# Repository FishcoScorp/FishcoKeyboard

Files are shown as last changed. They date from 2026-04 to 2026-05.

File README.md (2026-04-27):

# FishcoKeyboard
My keyboard for the program fallout by hackclub\
\
This keyboard was made with convieniece in mind, with 15 customizable macro keys (4 on left 11 on right) as well as a volume dial and small screen. 

# Table of Contents
Bill of Materials: https://github.com/FishcoScorp/FishcoKeyboard/edit/main/README.md#:~:text=Build_Files-,BOM,-.csv \
Photo Gallery: https://github.com/FishcoScorp/FishcoKeyboard/edit/main/README.md#:~:text=Fallout%20Zine.md-,Photo,-Gallery.md \
Code: https://github.com/FishcoScorp/FishcoKeyboard/edit/main/README.md#:~:text=README.md-,code,-.py \
Zine: https://github.com/FishcoScorp/FishcoKeyboard/edit/main/README.md#:~:text=BOM.csv-,Fallout,-Zine.md \
\
I am also in the process of working on a software that will interface with the keyboard and allow me to easily switch macro keys and the display on the screen, and make it easy to flash new code to the keyboard.\
\
Fallout Zine (1)
\
How to put it together! \
I used Kicad, and started by making a matrix with all the keys at about where I thought they were on a subsheet. That looks like this (Don't forget to add diodes too!!!) This works by wiring rows and columns which, when shorted by pressing a button, can be identified and pinpointed similar to using x and y on a graph so that it sends the correct input to your device!
Screenshot 2026-04-27 at 12 48 47 PM
\
Then I have the main schematic sheet, where I make all the rest of the connections. Using tags I connect the matrix to the ESP and also the screen and rotary encoder. Notice I connect the grounds of the latter two elements using a GND tag. This is because I am going to use a gnd fill later, which means the board will be coated in a thin layer of copper, removing the need for GND connections as this coating will serve that purpose.
Screenshot 2026-04-27 at 1 09 43 PM
\
Now bring it over to the PCB editor, where you will shape what your keyboard looks like. You can use an app called KB Placer by creating a layout beforehand on the website http://keyboard-layout-editor.com/ and then importing the JSON to KB placer. However, this did not work for me so I had to manually place everything and create the outline of the keyboard myself. I then connected the matrix, rotary encoder, and screen before adding the GND fill (the red in this photo)
Screenshot 2026-04-13 at 10 05 19 PM
\
Then it was time to cad a case. I used Fusion, using the exported .step file model to draw an outline for my case. Then I added some standoffs using the PCB as a reference with the screw holes I had placed earlier, ensuring stabilization but not breaking the PCB. In this case I made so both the bottom and top had walls so that it would look clean and sleek. I also sunk the keys into the keyboard a little so that it would look slim and cool. I also added a window into the ESP cause I think it would look really cool to be abe to see it, a little glimpse into the work/electronics that are required to make this a reality.
Screenshot 2026-04-16 at 11 17 34 AM
\ 
After this I designed my zine and submitted it, and here we are!

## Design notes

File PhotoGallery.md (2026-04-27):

Screenshot 2026-04-13 at 10 05 19 PM
Finished PCB design of the keyboard
Screenshot 2026-04-13 at 10 13 47 PM
Sketching out the design of the keyboard using the PCB as a reference in Fusion
Screenshot 2026-04-14 at 3 09 46 PM
Left a small gap for standoffs/avoid crushing diodes
Screenshot 2026-04-14 at 3 10 09 PM
Case bottom designed
Screenshot 2026-04-14 at 3 10 23 PM
Case bottom showing off standoff locations
Screenshot 2026-04-16 at 11 07 59 AM
Screenshot 2026-04-16 at 11 09 02 AM
Keys mapped out with fusion
Screenshot 2026-04-16 at 11 17 34 AM
Completed keyboard layout and holes
Screenshot 2026-04-20 at 1 21 00 PM
somehow managed to fit it all on one build plate using an H2D at my school

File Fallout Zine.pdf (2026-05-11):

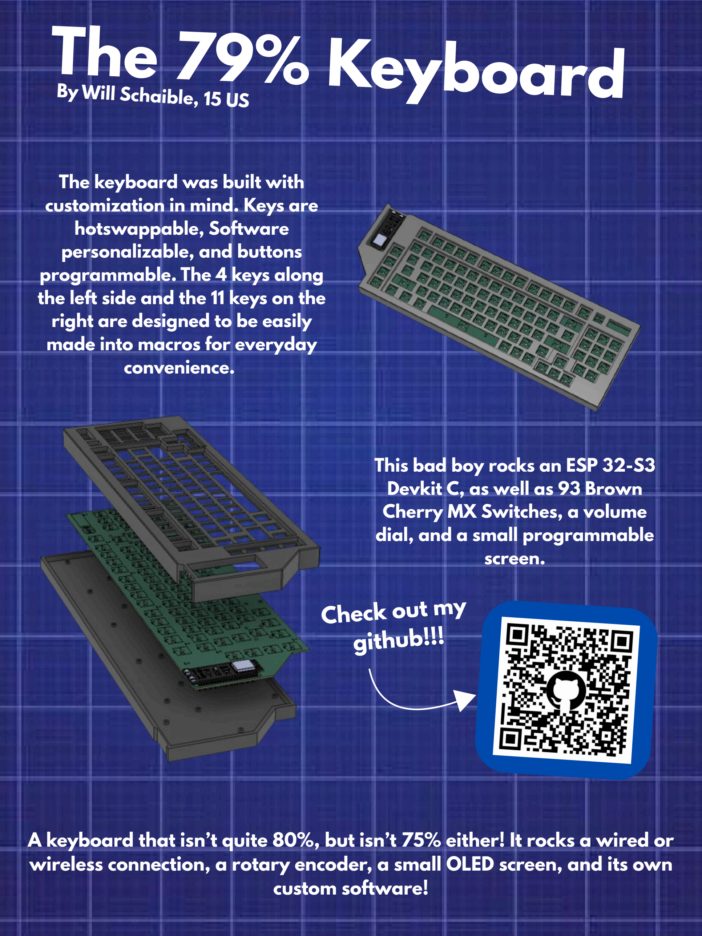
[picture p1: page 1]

T

By W

h

ill S

e

chaib

7

le, 15

9

US

# % Keyboard

A keyboard that isn’t quite 80%, but isn’t 75% either! It rocks a wired or wireless connection, a rotary encoder, a small OLED screen, and its own custom software!

The keyboard was built with customization in mind. Keys are hotswappable, Software
personalizable, and buttons programmable. The 4 keys along the left side and the 11 keys on the right are designed to be easily made into macros for everyday convenience.

This bad boy rocks an ESP 32-S3 Devkit C, as well as 93 Brown Cherry MX Switches, a volume dial, and a small programmable screen.

## Check out my github!!!

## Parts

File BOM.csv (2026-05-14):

Item | Quantity | Details | Unit Cost (USD) | Total Cost (USD) | Link
M2 Screws (3mm) | 22 | Mounting screws for PCB | $0.99 | $0.99 | https://www.aliexpress.us/item/3256802317314157.html?curPageLogUid=etorZpcxQGNX
Cherry MX Switches (Cheaper here) | 93 | Cherry MX2A Brown 55g tactile | $0.39 | $39.00 | https://mechanicalkeyboards.com/products/cherry-mx2a-brown-55g-tactile
ESP32-S3 Dev Board | 1 | ESP32-S3-DevKitC-1-N8 (8MB Flash + 8MB PSRAM) | $15.95 | $15.95 | https://www.adafruit.com/product/5312
Rotary Encoder | 1 | Standard rotary encoder | $6.58 | $6.58 | https://www.aliexpress.us/item/3256809594557634.html
OLED Screen | 1 | Small OLED display | $3.86 | $3.86 | https://www.aliexpress.us/item/3256806514926637.html
PCB Manufacturing | 1 | PCB + shipping from JLCPCB | $78.39 | $78.39 | https://jlcpcb.com/
PETG Filament (1kg) | 1 | PETG Basic with spool | $22.99 | $22.99 | https://us.store.bambulab.com/products/petg-basic?id=703099511296864275
TOTAL |  |  |  | $$167.76

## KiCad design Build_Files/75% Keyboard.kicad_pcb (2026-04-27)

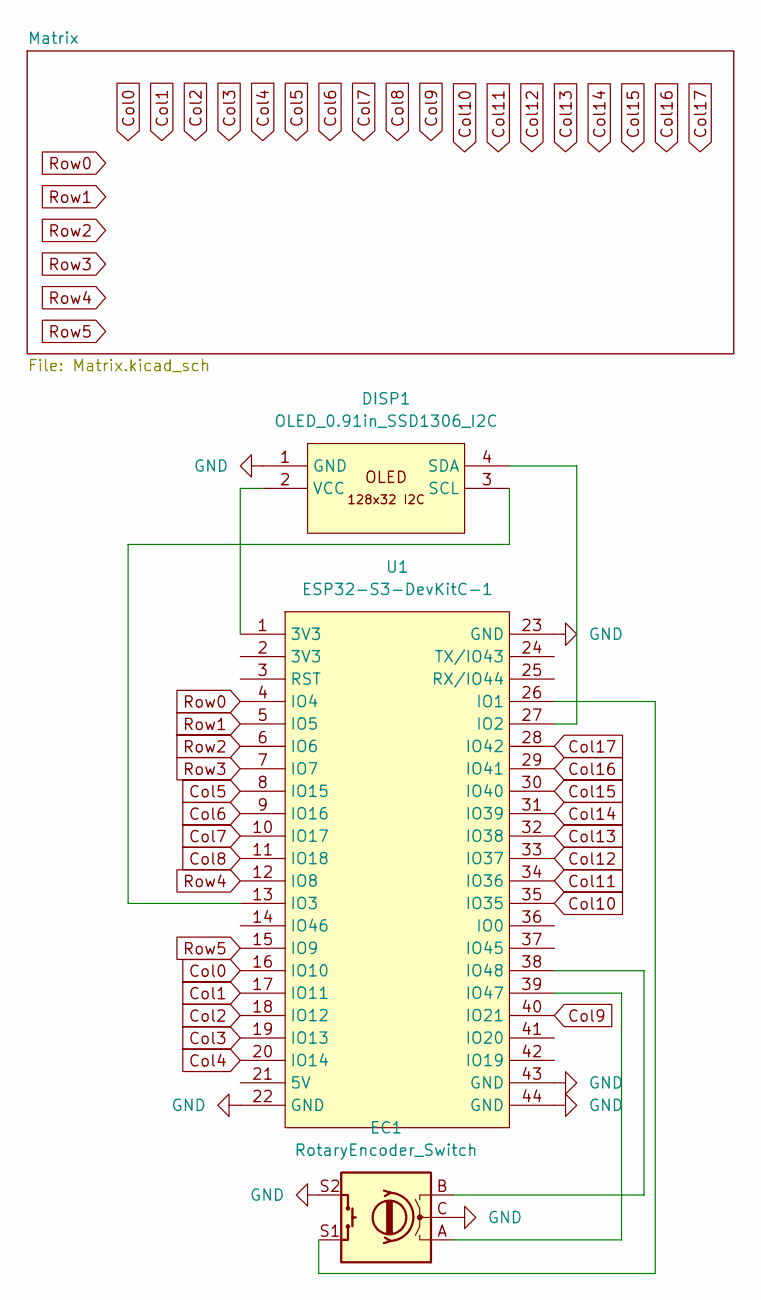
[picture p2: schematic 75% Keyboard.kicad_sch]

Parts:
DISP1: OLED_0.91in_SSD1306_I2C; OLED_0.91in_SSD1306_I2C_4Pin_P2.54mm
EC1: RotaryEncoder_Switch; RotaryEncoder_Alps_EC11E-Switch_Vertical_H20mm_MountingHoles
U1: ESP32-S3-DevKitC-1; ESP32-S3-DevKitC-1_2x22_P2.54mm

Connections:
Col0: U1.16 (IO10); also elsewhere on the board
Col1: U1.17 (IO11); also elsewhere on the board
Col2: U1.18 (IO12); also elsewhere on the board
Col3: U1.19 (IO13); also elsewhere on the board
Col4: U1.20 (IO14); also elsewhere on the board
Col5: U1.8 (IO15); also elsewhere on the board
Col6: U1.9 (IO16); also elsewhere on the board
Col7: U1.10 (IO17); also elsewhere on the board
Col8: U1.11 (IO18); also elsewhere on the board
Col9: U1.40 (IO21); also elsewhere on the board
Col10: U1.35 (IO35); also elsewhere on the board
Col11: U1.34 (IO36); also elsewhere on the board
Col12: U1.33 (IO37); also elsewhere on the board
Col13: U1.32 (IO38); also elsewhere on the board
Col14: U1.31 (IO39); also elsewhere on the board
Col15: U1.30 (IO40); also elsewhere on the board
Col16: U1.29 (IO41); also elsewhere on the board
Col17: U1.28 (IO42); also elsewhere on the board
GND: DISP1.1 (GND), EC1.C, EC1.S2, U1.22 (GND), U1.23 (GND), U1.43 (GND), U1.44 (GND)
unnamed: DISP1.3 (SCL), U1.13 (IO3)
unnamed: DISP1.4 (SDA), U1.27 (IO2)
unnamed: DISP1.2 (VCC), U1.1 (3V3)
unnamed: EC1.S1, U1.26 (IO1)
unnamed: EC1.A, U1.39 (IO47)
unnamed: EC1.B, U1.38 (IO48)
Row0: U1.4 (IO4); also elsewhere on the board
Row1: U1.5 (IO5); also elsewhere on the board
Row2: U1.6 (IO6); also elsewhere on the board
Row3: U1.7 (IO7); also elsewhere on the board
Row4: U1.12 (IO8); also elsewhere on the board
Row5: U1.15 (IO9); also elsewhere on the board

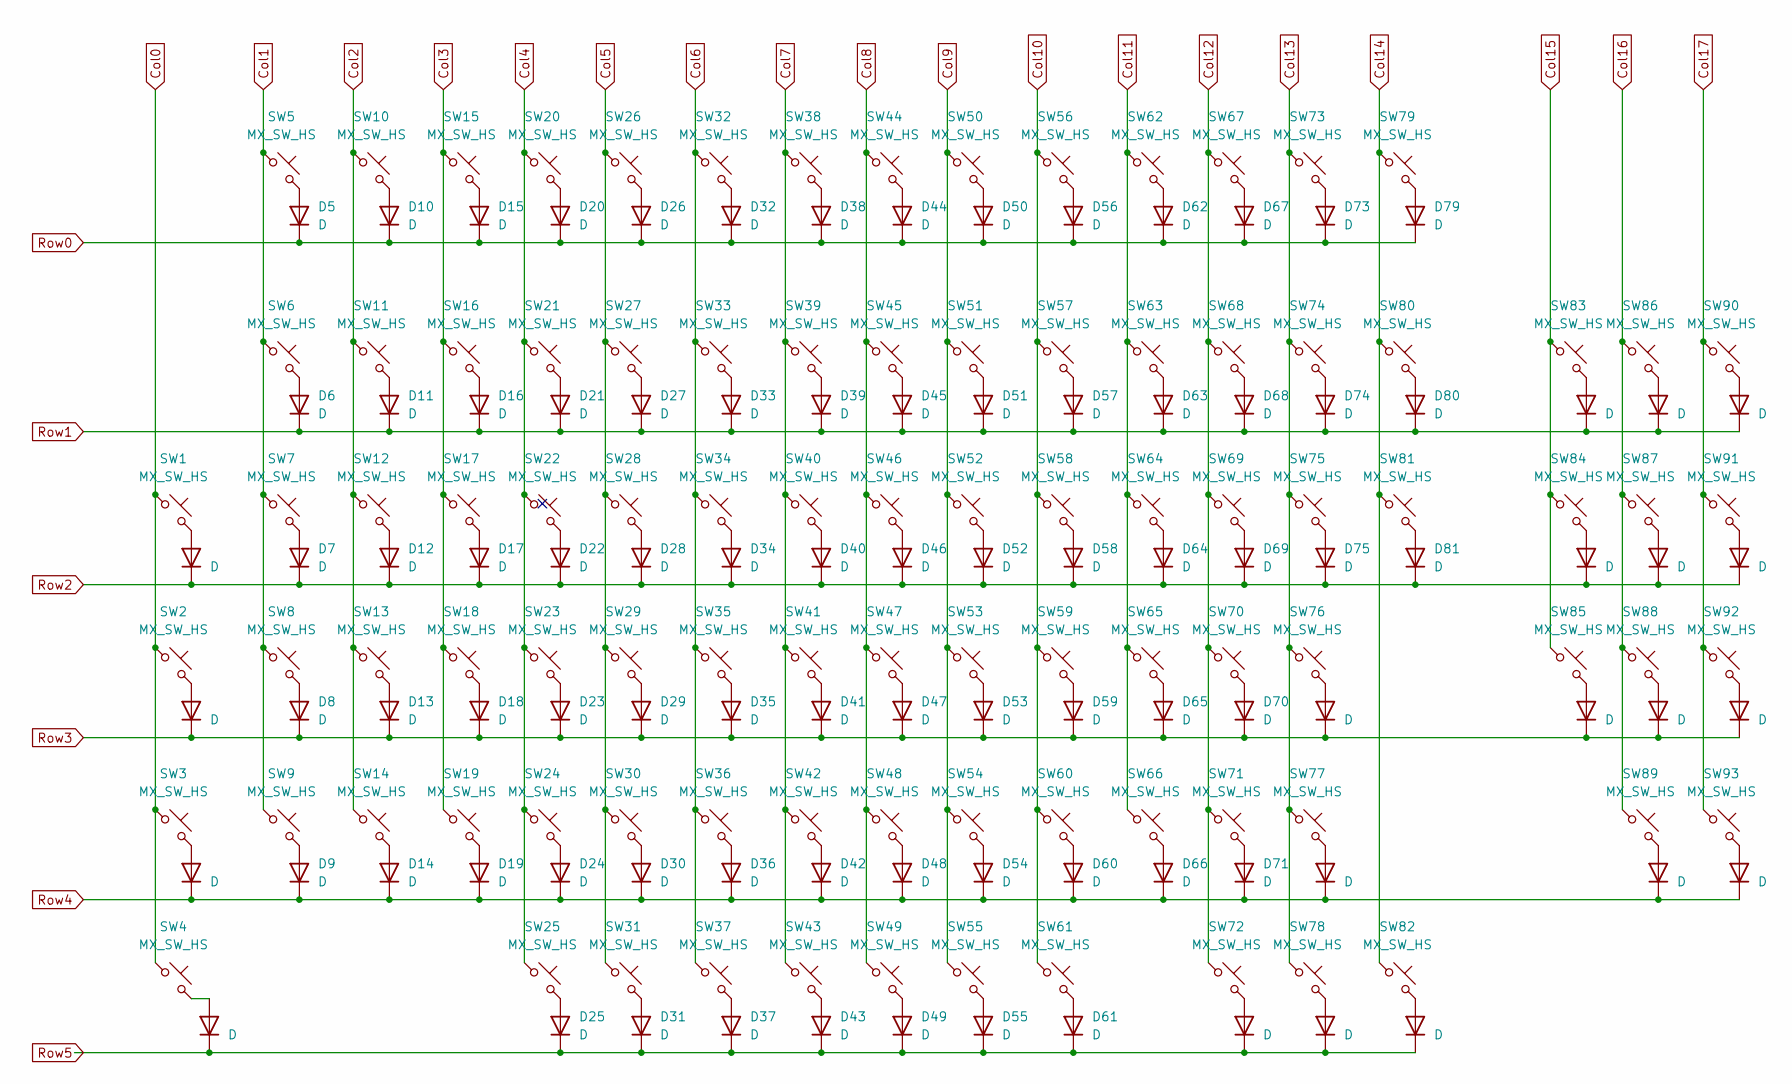
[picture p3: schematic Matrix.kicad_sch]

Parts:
D1, D2, D3, D4, D5, D6, D7, D8, D9, D10, D11, D12, D13, D14, D15, D16, D17, D18, D19, D20, D21, D22, D23, D24, D25, D26, D27, D28, D29, D30, D31, D32, D33, D34, D35, D36, D37, D38, D39, D40, D41, D42, D43, D44, D45, D46, D47, D48, D49, D50, D51, D52, D53, D54, D55, D56, D57, D58, D59, D60, D61, D62, D63, D64, D65, D66, D67, D68, D69, D70, D71, D72, D73, D74, D75, D76, D77, D78, D79, D80, D81, D82, D83, D84, D85, D86, D87, D88, D89, D90, D91, D92, D93: D; D_SOD-123
SW1, SW2, SW3, SW4, SW5, SW6, SW10, SW11, SW12, SW13, SW14, SW15, SW16, SW17, SW18, SW19, SW20, SW21, SW22, SW23, SW24, SW26, SW27, SW28, SW29, SW30, SW32, SW33, SW34, SW35, SW36, SW38, SW39, SW40, SW41, SW42, SW44, SW45, SW46, SW47, SW48, SW49, SW50, SW51, SW52, SW53, SW54, SW55, SW56, SW57, SW58, SW59, SW60, SW61, SW62, SW63, SW64, SW65, SW66, SW67, SW68, SW69, SW70, SW72, SW73, SW74, SW75, SW77, SW78, SW79, SW82, SW83, SW84, SW85, SW86, SW87, SW88, SW89, SW90, SW91, SW92, SW93: MX_SW_HS; SW_Cherry_MX_1.00u_PCB
SW7, SW81: MX_SW_HS; SW_Cherry_MX_1.50u_PCB
SW8, SW71: MX_SW_HS; SW_Cherry_MX_1.75u_PCB
SW9, SW76: MX_SW_HS; SW_Cherry_MX_2.25u_PCB
SW25, SW31, SW37: MX_SW_HS; SW_Cherry_MX_1.25u_PCB
SW43: MX_SW_HS; SW_Cherry_MX_6.25u_PCB
SW80: MX_SW_HS; SW_Cherry_MX_2.00u_PCB

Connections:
Col0: SW1.1, SW2.1, SW3.1, SW4.1; also elsewhere on the board
Col1: SW5.1, SW6.1, SW7.1, SW8.1, SW9.1; also elsewhere on the board
Col2: SW10.1, SW11.1, SW12.1, SW13.1, SW14.1; also elsewhere on the board
Col3: SW15.1, SW16.1, SW17.1, SW18.1, SW19.1; also elsewhere on the board
Col4: SW20.1, SW21.1, SW22.1, SW23.1, SW24.1, SW25.1; also elsewhere on the board
Col5: SW26.1, SW27.1, SW28.1, SW29.1, SW30.1, SW31.1; also elsewhere on the board
Col6: SW32.1, SW33.1, SW34.1, SW35.1, SW36.1, SW37.1; also elsewhere on the board
Col7: SW38.1, SW39.1, SW40.1, SW41.1, SW42.1, SW43.1; also elsewhere on the board
Col8: SW44.1, SW45.1, SW46.1, SW47.1, SW48.1, SW49.1; also elsewhere on the board
Col9: SW50.1, SW51.1, SW52.1, SW53.1, SW54.1, SW55.1; also elsewhere on the board
Col10: SW56.1, SW57.1, SW58.1, SW59.1, SW60.1, SW61.1; also elsewhere on the board
Col11: SW62.1, SW63.1, SW64.1, SW65.1, SW66.1; also elsewhere on the board
Col12: SW67.1, SW68.1, SW69.1, SW70.1, SW71.1, SW72.1; also elsewhere on the board
Col13: SW73.1, SW74.1, SW75.1, SW76.1, SW77.1, SW78.1; also elsewhere on the board
Col14: SW79.1, SW80.1, SW81.1, SW82.1; also elsewhere on the board
Col15: SW83.1, SW84.1, SW85.1; also elsewhere on the board
Col16: SW86.1, SW87.1, SW88.1, SW89.1; also elsewhere on the board
Col17: SW90.1, SW91.1, SW92.1, SW93.1; also elsewhere on the board
unnamed: D1.2 (A), SW1.2
unnamed: D2.2 (A), SW2.2
unnamed: D3.2 (A), SW3.2
unnamed: D4.2 (A), SW4.2
unnamed: D5.2 (A), SW5.2
unnamed: D6.2 (A), SW6.2
unnamed: D7.2 (A), SW7.2
unnamed: D8.2 (A), SW8.2
unnamed: D9.2 (A), SW9.2
unnamed: D10.2 (A), SW10.2
unnamed: D11.2 (A), SW11.2
unnamed: D12.2 (A), SW12.2
unnamed: D13.2 (A), SW13.2
unnamed: D14.2 (A), SW14.2
unnamed: D15.2 (A), SW15.2
unnamed: D16.2 (A), SW16.2
unnamed: D17.2 (A), SW17.2
unnamed: D18.2 (A), SW18.2
unnamed: D19.2 (A), SW19.2
unnamed: D20.2 (A), SW20.2
unnamed: D21.2 (A), SW21.2
unnamed: D22.2 (A), SW22.2
unnamed: D23.2 (A), SW23.2
unnamed: D24.2 (A), SW24.2
unnamed: D25.2 (A), SW25.2
unnamed: D26.2 (A), SW26.2
unnamed: D27.2 (A), SW27.2
unnamed: D28.2 (A), SW28.2
unnamed: D29.2 (A), SW29.2
unnamed: D30.2 (A), SW30.2
unnamed: D31.2 (A), SW31.2
unnamed: D32.2 (A), SW32.2
unnamed: D33.2 (A), SW33.2
unnamed: D34.2 (A), SW34.2
unnamed: D35.2 (A), SW35.2
unnamed: D36.2 (A), SW36.2
unnamed: D37.2 (A), SW37.2
unnamed: D38.2 (A), SW38.2
unnamed: D39.2 (A), SW39.2
unnamed: D40.2 (A), SW40.2
unnamed: D41.2 (A), SW41.2
unnamed: D42.2 (A), SW42.2
unnamed: D43.2 (A), SW43.2
unnamed: D44.2 (A), SW44.2
unnamed: D45.2 (A), SW45.2
unnamed: D46.2 (A), SW46.2
unnamed: D47.2 (A), SW47.2
unnamed: D48.2 (A), SW48.2
unnamed: D49.2 (A), SW49.2
unnamed: D50.2 (A), SW50.2
unnamed: D51.2 (A), SW51.2
unnamed: D52.2 (A), SW52.2
unnamed: D53.2 (A), SW53.2
unnamed: D54.2 (A), SW54.2
unnamed: D55.2 (A), SW55.2
unnamed: D56.2 (A), SW56.2
unnamed: D57.2 (A), SW57.2
unnamed: D58.2 (A), SW58.2
unnamed: D59.2 (A), SW59.2
unnamed: D60.2 (A), SW60.2
unnamed: D61.2 (A), SW61.2
unnamed: D62.2 (A), SW62.2
unnamed: D63.2 (A), SW63.2
unnamed: D64.2 (A), SW64.2
unnamed: D65.2 (A), SW65.2
unnamed: D66.2 (A), SW66.2
unnamed: D67.2 (A), SW67.2
unnamed: D68.2 (A), SW68.2
unnamed: D69.2 (A), SW69.2
unnamed: D70.2 (A), SW70.2
unnamed: D71.2 (A), SW71.2
unnamed: D72.2 (A), SW72.2
unnamed: D73.2 (A), SW73.2
unnamed: D74.2 (A), SW74.2
unnamed: D75.2 (A), SW75.2
unnamed: D76.2 (A), SW76.2
unnamed: D77.2 (A), SW77.2
unnamed: D78.2 (A), SW78.2
unnamed: D79.2 (A), SW79.2
unnamed: D80.2 (A), SW80.2
unnamed: D81.2 (A), SW81.2
unnamed: D82.2 (A), SW82.2
unnamed: D83.2 (A), SW83.2
unnamed: D84.2 (A), SW84.2
unnamed: D85.2 (A), SW85.2
unnamed: D86.2 (A), SW86.2
unnamed: D87.2 (A), SW87.2
unnamed: D88.2 (A), SW88.2
unnamed: D89.2 (A), SW89.2
unnamed: D90.2 (A), SW90.2
unnamed: D91.2 (A), SW91.2
unnamed: D92.2 (A), SW92.2
unnamed: D93.2 (A), SW93.2
Row0: D5.1 (K), D10.1 (K), D15.1 (K), D20.1 (K), D26.1 (K), D32.1 (K), D38.1 (K), D44.1 (K), D50.1 (K), D56.1 (K), D62.1 (K), D67.1 (K), D73.1 (K), D79.1 (K); also elsewhere on the board
Row1: D6.1 (K), D11.1 (K), D16.1 (K), D21.1 (K), D27.1 (K), D33.1 (K), D39.1 (K), D45.1 (K), D51.1 (K), D57.1 (K), D63.1 (K), D68.1 (K), D74.1 (K), D80.1 (K), D83.1 (K), D86.1 (K), D90.1 (K); also elsewhere on the board
Row2: D1.1 (K), D7.1 (K), D12.1 (K), D17.1 (K), D22.1 (K), D28.1 (K), D34.1 (K), D40.1 (K), D46.1 (K), D52.1 (K), D58.1 (K), D64.1 (K), D69.1 (K), D75.1 (K), D81.1 (K), D84.1 (K), D87.1 (K), D91.1 (K); also elsewhere on the board
Row3: D2.1 (K), D8.1 (K), D13.1 (K), D18.1 (K), D23.1 (K), D29.1 (K), D35.1 (K), D41.1 (K), D47.1 (K), D53.1 (K), D59.1 (K), D65.1 (K), D70.1 (K), D76.1 (K), D85.1 (K), D88.1 (K), D92.1 (K); also elsewhere on the board
Row4: D3.1 (K), D9.1 (K), D14.1 (K), D19.1 (K), D24.1 (K), D30.1 (K), D36.1 (K), D42.1 (K), D48.1 (K), D54.1 (K), D60.1 (K), D66.1 (K), D71.1 (K), D77.1 (K), D89.1 (K), D93.1 (K); also elsewhere on the board
Row5: D4.1 (K), D25.1 (K), D31.1 (K), D37.1 (K), D43.1 (K), D49.1 (K), D55.1 (K), D61.1 (K), D72.1 (K), D78.1 (K), D82.1 (K); also elsewhere on the board

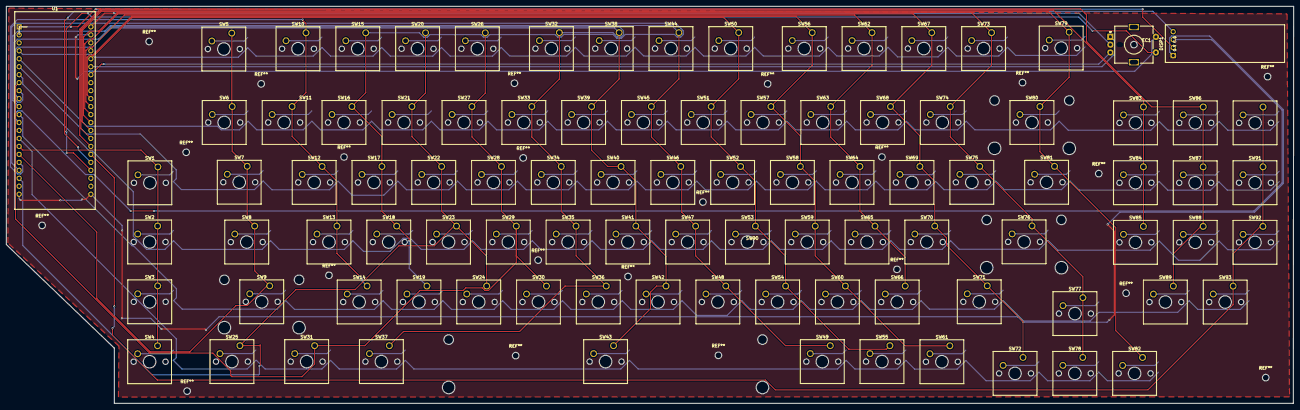
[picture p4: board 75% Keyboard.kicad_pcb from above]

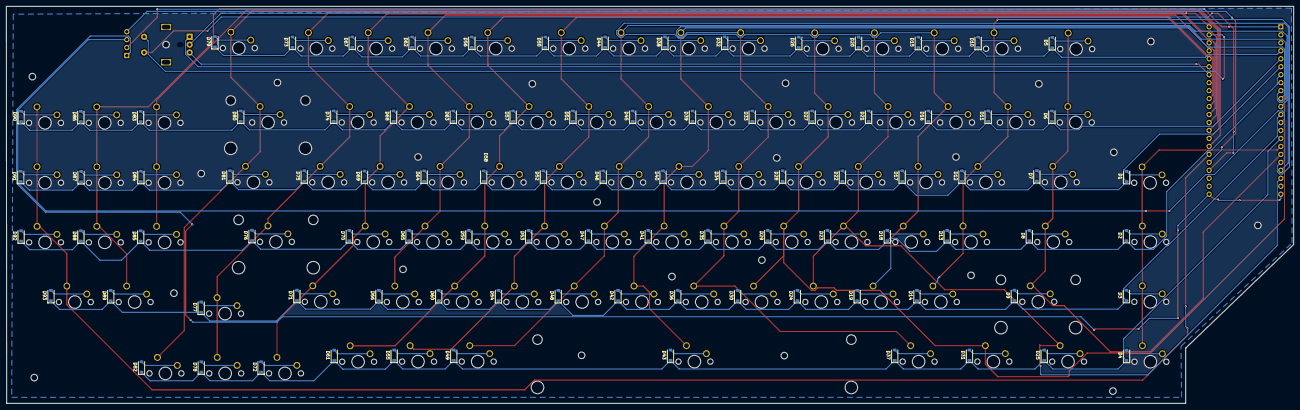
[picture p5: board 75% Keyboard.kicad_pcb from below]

Board: 2 copper layers, 410.2 x 126.5 mm, 189 parts (93 on the bottom side), 124 nets.

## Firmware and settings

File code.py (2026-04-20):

import time

import board
import busio
import digitalio
import keypad
import rotaryio
import usb_hid

from adafruit_hid.consumer_control import ConsumerControl
from adafruit_hid.consumer_control_code import ConsumerControlCode
from adafruit_hid.keyboard import Keyboard
from adafruit_hid.keycode import Keycode


ROW_PINS = (
    board.IO4,
    board.IO5,
    board.IO6,
    board.IO7,
    board.IO8,
    board.IO9,
)

COL_PINS = (
    board.IO10,
    board.IO11,
    board.IO12,
    board.IO13,
    board.IO14,
    board.IO15,
    board.IO16,
    board.IO17,
    board.IO18,
    board.IO21,
    board.IO35,
    board.IO36,
    board.IO37,
    board.IO38,
    board.IO39,
    board.IO40,
    board.IO41,
    board.IO42,
)

ENCODER_A = board.IO47
ENCODER_B = board.IO48
ENCODER_BUTTON = board.IO1

OLED_SCL = board.IO3
OLED_SDA = board.IO2

ROW_COUNT = len(ROW_PINS)
COL_COUNT = len(COL_PINS)


def build_keymap():
    no = None
    action = lambda name: ("action", name)

    rows = [
        [
            no,
            Keycode.ESCAPE,
            Keycode.F1,
            Keycode.F2,
            Keycode.F3,
            Keycode.F4,
            Keycode.F5,
            Keycode.F6,
            Keycode.F7,
            Keycode.F8,
            Keycode.F9,
            Keycode.F10,
            Keycode.F11,
            Keycode.F12,
            action("ALT_F4_MACRO"),
            no,
            no,
            no,
        ],
        [
            no,
            Keycode.GRAVE_ACCENT,
            Keycode.ONE,
            Keycode.TWO,
            Keycode.THREE,
            Keycode.FOUR,
            Keycode.FIVE,
            Keycode.SIX,
            Keycode.SEVEN,
            Keycode.EIGHT,
            Keycode.NINE,
            Keycode.ZERO,
            Keycode.MINUS,
            Keycode.EQUALS,
            Keycode.BACKSPACE,
            action("MEDIA_PREV"),
            action("MEDIA_PLAY_PAUSE"),
            action("MEDIA_NEXT"),
        ],
        [
            action("UNASSIGNED_1"),
            Keycode.TAB,
            Keycode.Q,
            Keycode.W,
            Keycode.E,
            Keycode.R,
            Keycode.T,
            Keycode.Y,
            Keycode.U,
            Keycode.I,
            Keycode.O,
            Keycode.P,
            Keycode.LEFT_BRACKET,
            Keycode.RIGHT_BRACKET,
            Keycode.BACKSLASH,
            action("OPEN_SETTINGS"),
            action("OPEN_DISCORD"),
            action("OPEN_SPOTIFY"),
        ],
        [
            action("UNASSIGNED_2"),
            Keycode.CAPS_LOCK,
            Keycode.A,
            Keycode.S,
            Keycode.D,
            Keycode.F,
            Keycode.G,
            Keycode.H,
            Keycode.J,
            Keycode.K,
            Keycode.L,
            Keycode.SEMICOLON,
            Keycode.QUOTE,
            Keycode.ENTER,
            no,
            action("MEDIA_MUTE"),
            action("DISCORD_DEAFEN"),
            action("LEDS_TOGGLE"),
        ],
        [
            action("UNASSIGNED_3"),
            Keycode.LEFT_SHIFT,
            Keycode.Z,
            Keycode.X,
            Keycode.C,
            Keycode.V,
            Keycode.B,
            Keycode.N,
            Keycode.M,
            Keycode.COMMA,
            Keycode.PERIOD,
            Keycode.FORWARD_SLASH,
            Keycode.RIGHT_SHIFT,
            Keycode.UP_ARROW,
            no,
            no,
            action("COPY"),
            action("PASTE"),
        ],
        [
            action("UNASSIGNED_4"),
            no,
            no,
            no,
            Keycode.LEFT_CONTROL,
            Keycode.LEFT_GUI,
            Keycode.LEFT_ALT,
            Keycode.SPACEBAR,
            Keycode.RIGHT_ALT,
            action("FN_LAYER"),
            Keycode.RIGHT_CONTROL,
            Keycode.LEFT_ARROW,
            Keycode.DOWN_ARROW,
            Keycode.RIGHT_ARROW,
            no,
            no,
            no,
            no,
            no,
            no,
        ],
    ]

    flattened = [code for row in rows for code in row]
    if len(flattened) != ROW_COUNT * COL_COUNT:
        raise ValueError("Keymap dimensions do not match matrix size")
    return flattened


KEYMAP = build_keymap()


def key_number_to_keycode(key_number):
    return KEYMAP[key_number]


def setup_display():
    try:
        import displayio
        import terminalio
        from adafruit_display_text import label
        from adafruit_displayio_ssd1306 import SSD1306
    except ImportError:
        return None

    displayio.release_displays()

    i2c = busio.I2C(OLED_SCL, OLED_SDA)
    display_bus = displayio.I2CDisplay(i2c, device_address=0x3C)
    display = SSD1306(display_bus, width=128, height=32)

    splash = displayio.Group()
    text = label.Label(terminalio.FONT, text="HELLO WORLD", color=0xFFFFFF, x=8, y=16)
    splash.append(text)
    display.root_group = splash
    return display


keyboard = Keyboard(usb_hid.devices)
consumer = ConsumerControl(usb_hid.devices)

matrix = keypad.KeyMatrix(
    row_pins=ROW_PINS,
    column_pins=COL_PINS,
    columns_to_anodes=True,
)

encoder = rotaryio.IncrementalEncoder(ENCODER_A, ENCODER_B)
last_encoder_position = encoder.position

encoder_button = digitalio.DigitalInOut(ENCODER_BUTTON)
encoder_button.direction = digitalio.Direction.INPUT
encoder_button.pull = digitalio.Pull.UP
last_button_value = encoder_button.value

display = setup_display()
pressed_counts = {}


def send_combo(*keycodes):
    keyboard.press(*keycodes)
    keyboard.release_all()


def handle_custom_action(action_name):
    if action_name.startswith("UNASSIGNED_"):
        # Reserved side buttons; assign behavior here later.
        return

    if action_name == "ALT_F4_MACRO":
        send_combo(Keycode.LEFT_ALT, Keycode.F4)
    elif action_name == "MEDIA_PREV":
        consumer.send(ConsumerControlCode.SCAN_PREVIOUS_TRACK)
    elif action_name == "MEDIA_PLAY_PAUSE":
        consumer.send(ConsumerControlCode.PLAY_PAUSE)
    elif action_name == "MEDIA_NEXT":
        consumer.send(ConsumerControlCode.SCAN_NEXT_TRACK)
    elif action_name == "OPEN_SETTINGS":
        send_combo(Keycode.LEFT_GUI, Keycode.I)
    elif action_name == "OPEN_DISCORD":
        # Placeholder for host-side automation or remapping.
        return
    elif action_name == "OPEN_SPOTIFY":
        # Placeholder for host-side automation or remapping.
        return
    elif action_name == "FN_LAYER":
        # Placeholder for an additional layer later.
        return
    elif action_name == "MEDIA_MUTE":
        consumer.send(ConsumerControlCode.MUTE)
    elif action_name == "DISCORD_DEAFEN":
        # Placeholder for host-side automation or remapping.
        return
    elif action_name == "LEDS_TOGGLE":
        # Placeholder for lighting control later.
        return
    elif action_name == "COPY":
        send_combo(Keycode.LEFT_CONTROL, Keycode.C)
    elif action_name == "PASTE":
        send_combo(Keycode.LEFT_CONTROL, Keycode.V)


def press_key(keycode):
    if keycode is None:
        return

    if isinstance(keycode, tuple) and keycode[0] == "action":
        handle_custom_action(keycode[1])
        return

    count = pressed_counts.get(keycode, 0)
    if count == 0:
        keyboard.press(keycode)
    pressed_counts[keycode] = count + 1


def release_key(keycode):
    if keycode is None:
        return

    if isinstance(keycode, tuple) and keycode[0] == "action":
        return

    count = pressed_counts.get(keycode, 0)
    if count <= 1:
        pressed_counts.pop(keycode, None)
        keyboard.release(keycode)
    else:
        pressed_counts[keycode] = count - 1


def handle_matrix_events():
    while True:
        event = matrix.events.get()
        if event is None:
            return

        keycode = key_number_to_keycode(event.key_number)
        if event.pressed:
            press_key(keycode)
        elif event.released:
            release_key(keycode)


def handle_encoder():
    global last_encoder_position

    position = encoder.position
    delta = position - last_encoder_position
    if delta > 0:
        for _ in range(delta):
            consumer.send(ConsumerControlCode.VOLUME_INCREMENT)
    elif delta < 0:
        for _ in range(-delta):
            consumer.send(ConsumerControlCode.VOLUME_DECREMENT)
    last_encoder_position = position


def handle_encoder_button():
    global last_button_value

    current_value = encoder_button.value
    if last_button_value and not current_value:
        consumer.send(ConsumerControlCode.MUTE)
    last_button_value = current_value


while True:
    handle_matrix_events()
    handle_encoder()
    handle_encoder_button()
    time.sleep(0.001)

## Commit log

2026-04-20 Format BOM.md for better readability
2026-04-20 Fix formatting and update purchase links in BOM.md
2026-04-20 Add keyboard matrix and rotary encoder functionality
    Implement a keyboard matrix with rotary encoder support and OLED display.
2026-04-20 Update BOM with new materials and costs
2026-04-20 Add PETG material link to BOM
2026-04-27 Rename 75% Keyboard.kicad_pcb to Build_Files/75% Keyboard.kicad_pcb
    [75% Keyboard.kicad_pcb]
2026-04-27 Rename 75% Keyboard.kicad_pcb.zip to Build_Files /75%Keyboard.kicad_pcb.zip
2026-04-27 Insert image in Fallout Zine.md
    Add an image to the Fallout Zine document.
2026-04-27 Add Table of Contents to README
    Added a Table of Contents with links to the Bill of Materials, Photo Gallery, Code, and Zine.
2026-04-27 Format BOM.csv for better readability
    [BOM.csv]
2026-04-27 Add purchase links and update total cost in BOM
    Updated BOM with purchase links for each part and adjusted total cost.
    [BOM.csv]
2026-04-27 Update BOM.csv with new part entries
    [BOM.csv]
2026-05-14 Update PCB manufacturing supplier and total cost
    [BOM.csv]
